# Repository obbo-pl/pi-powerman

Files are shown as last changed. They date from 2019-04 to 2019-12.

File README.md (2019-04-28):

# Pi-Powerman
  The main goal is to create a universal service operating with Raspberry Pi allowing you to control the power system. Of course, the power supply must be compatible in terms of how to communicate with the service. The current version uses I2C and two I/O ports for this purpose. The solution consists of: a service running on Raspberry and a microcontroller power supply co-operating with it. 

##### Main features:
- Easy adaptation of the power supply system,
- UPS function, automatic switching to backup power supply, battery charging and charging status monitoring,
- Automatic "shutdown" after power loss,
- Up to 8 buttons with LED (1 power button and 7 user defined),
- Ability to define extended scenarios for buttons,
- LEDs automatically indicate the state of buttons and related scenarios,
- Up to 8 connected power circuits (including 1 dedicated for Raspberry Pi),
- Cut off the power after shutting down the system,
- Monitoring of voltage, power consumption, UPS status, temperature and battery voltage,
- Export of monitored values to RRD and .txt files, .csv,
- IoT, sending messages by the MQTT protocol, 
- Communication with Raspberry via I2C and two dedicated I/O ports,
- Dedicated LED for power and Raspberry status indication.

### Requirements:
- Python 3
- Raspbian Jessie or newer

### Installation:
```
sudo apt-get update
sudo apt-get install python3-yaml python3-pip librrd-dev
sudo python3 -m pip install RPi.GPIO smbus rrdtool schedule paho-mqtt

cd /tmp
wget https://www.obbo.pl/files/articles/pi-powerman/pi-powerman.tgz
sudo mkdir /usr/local/pi-powerman
sudo tar -xf pi-powerman.tgz -C /usr/local/pi-powerman/

cd /etc/systemd/system/ 
sudo ln -s /usr/local/pi-powerman/pi-powerman.service pi-powerman.service

sudo systemctl daemon-reload
sudo systemctl enable pi-powerman.service
sudo systemctl start pi-powerman.service
```

### Hardware & Firmware.
These sections covers info on building sample hardware, including schematics, PCBs, and the corresponding firmware.

For more information: [www.obbo.pl](http://www.obbo.pl/pi-powerman)

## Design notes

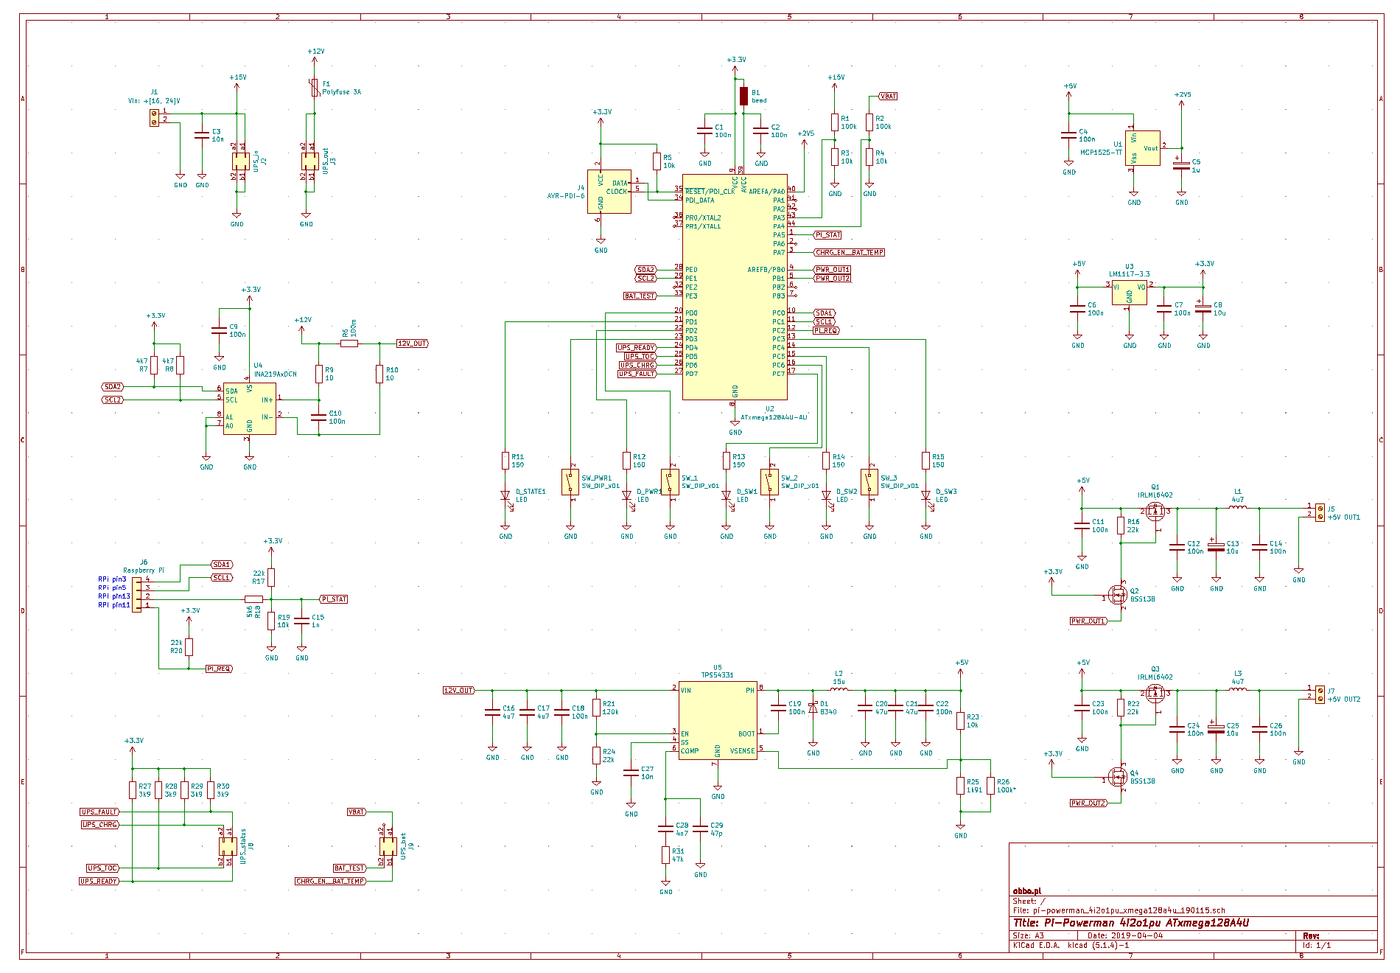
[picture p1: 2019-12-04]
hardware/pi-powerman_4i2o1pu_xmega128a4u_190115/pi-powerman_4i2o1pu_xmega128a4u_190115.png

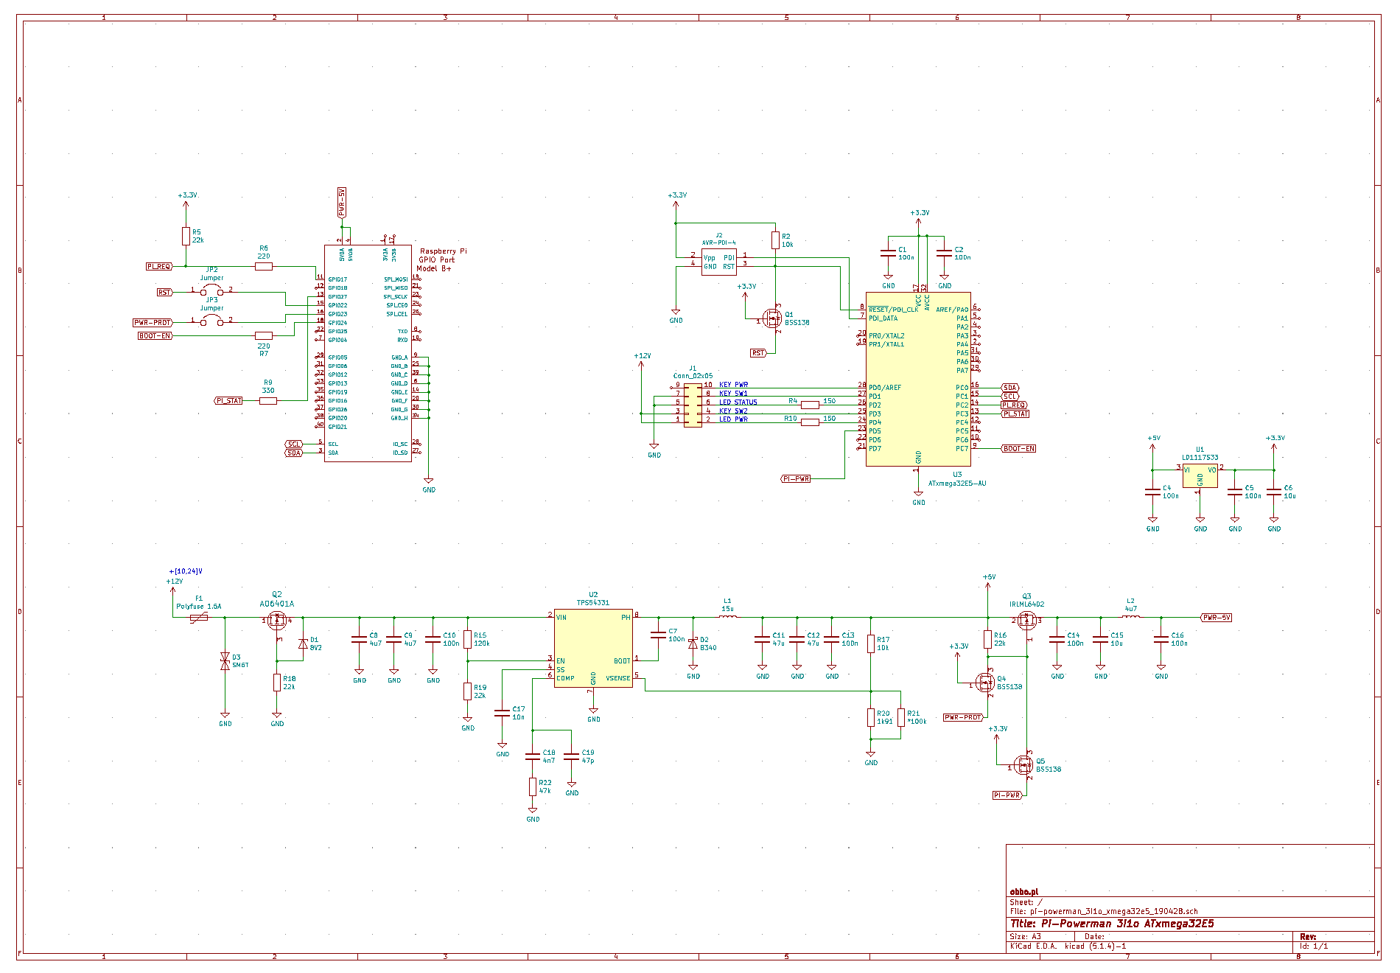
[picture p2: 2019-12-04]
hardware/pi-powerman_3i1o_xmega32e5_190428/pi-powerman_3i1o_xmega32e5_190428.png

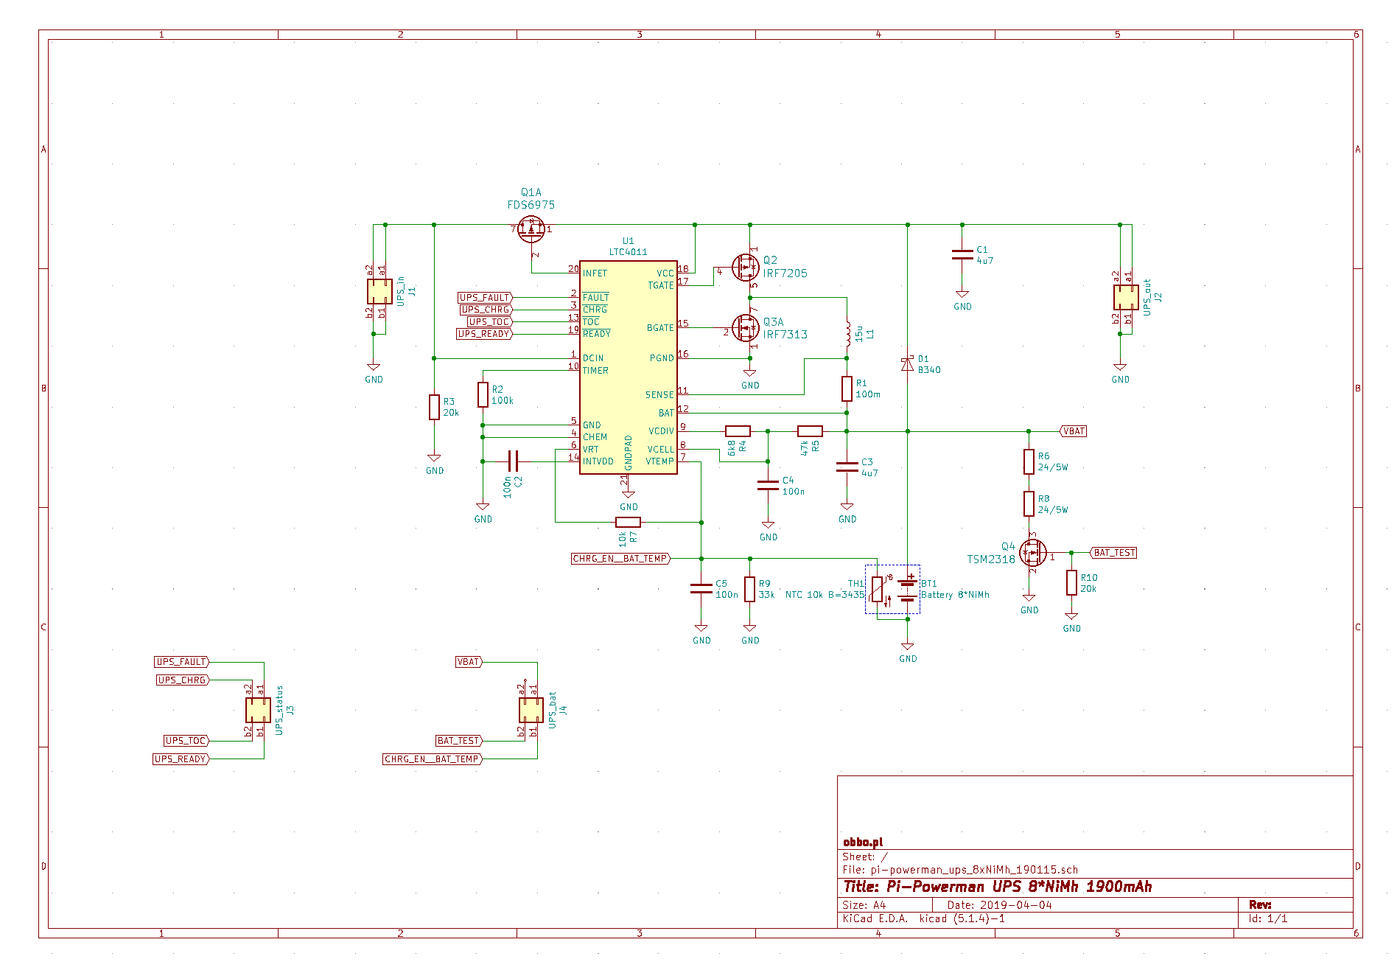
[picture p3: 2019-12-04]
hardware/pi-powerman_ups_8xNiMh_190115/pi-powerman_ups_8xNiMh_190115.png

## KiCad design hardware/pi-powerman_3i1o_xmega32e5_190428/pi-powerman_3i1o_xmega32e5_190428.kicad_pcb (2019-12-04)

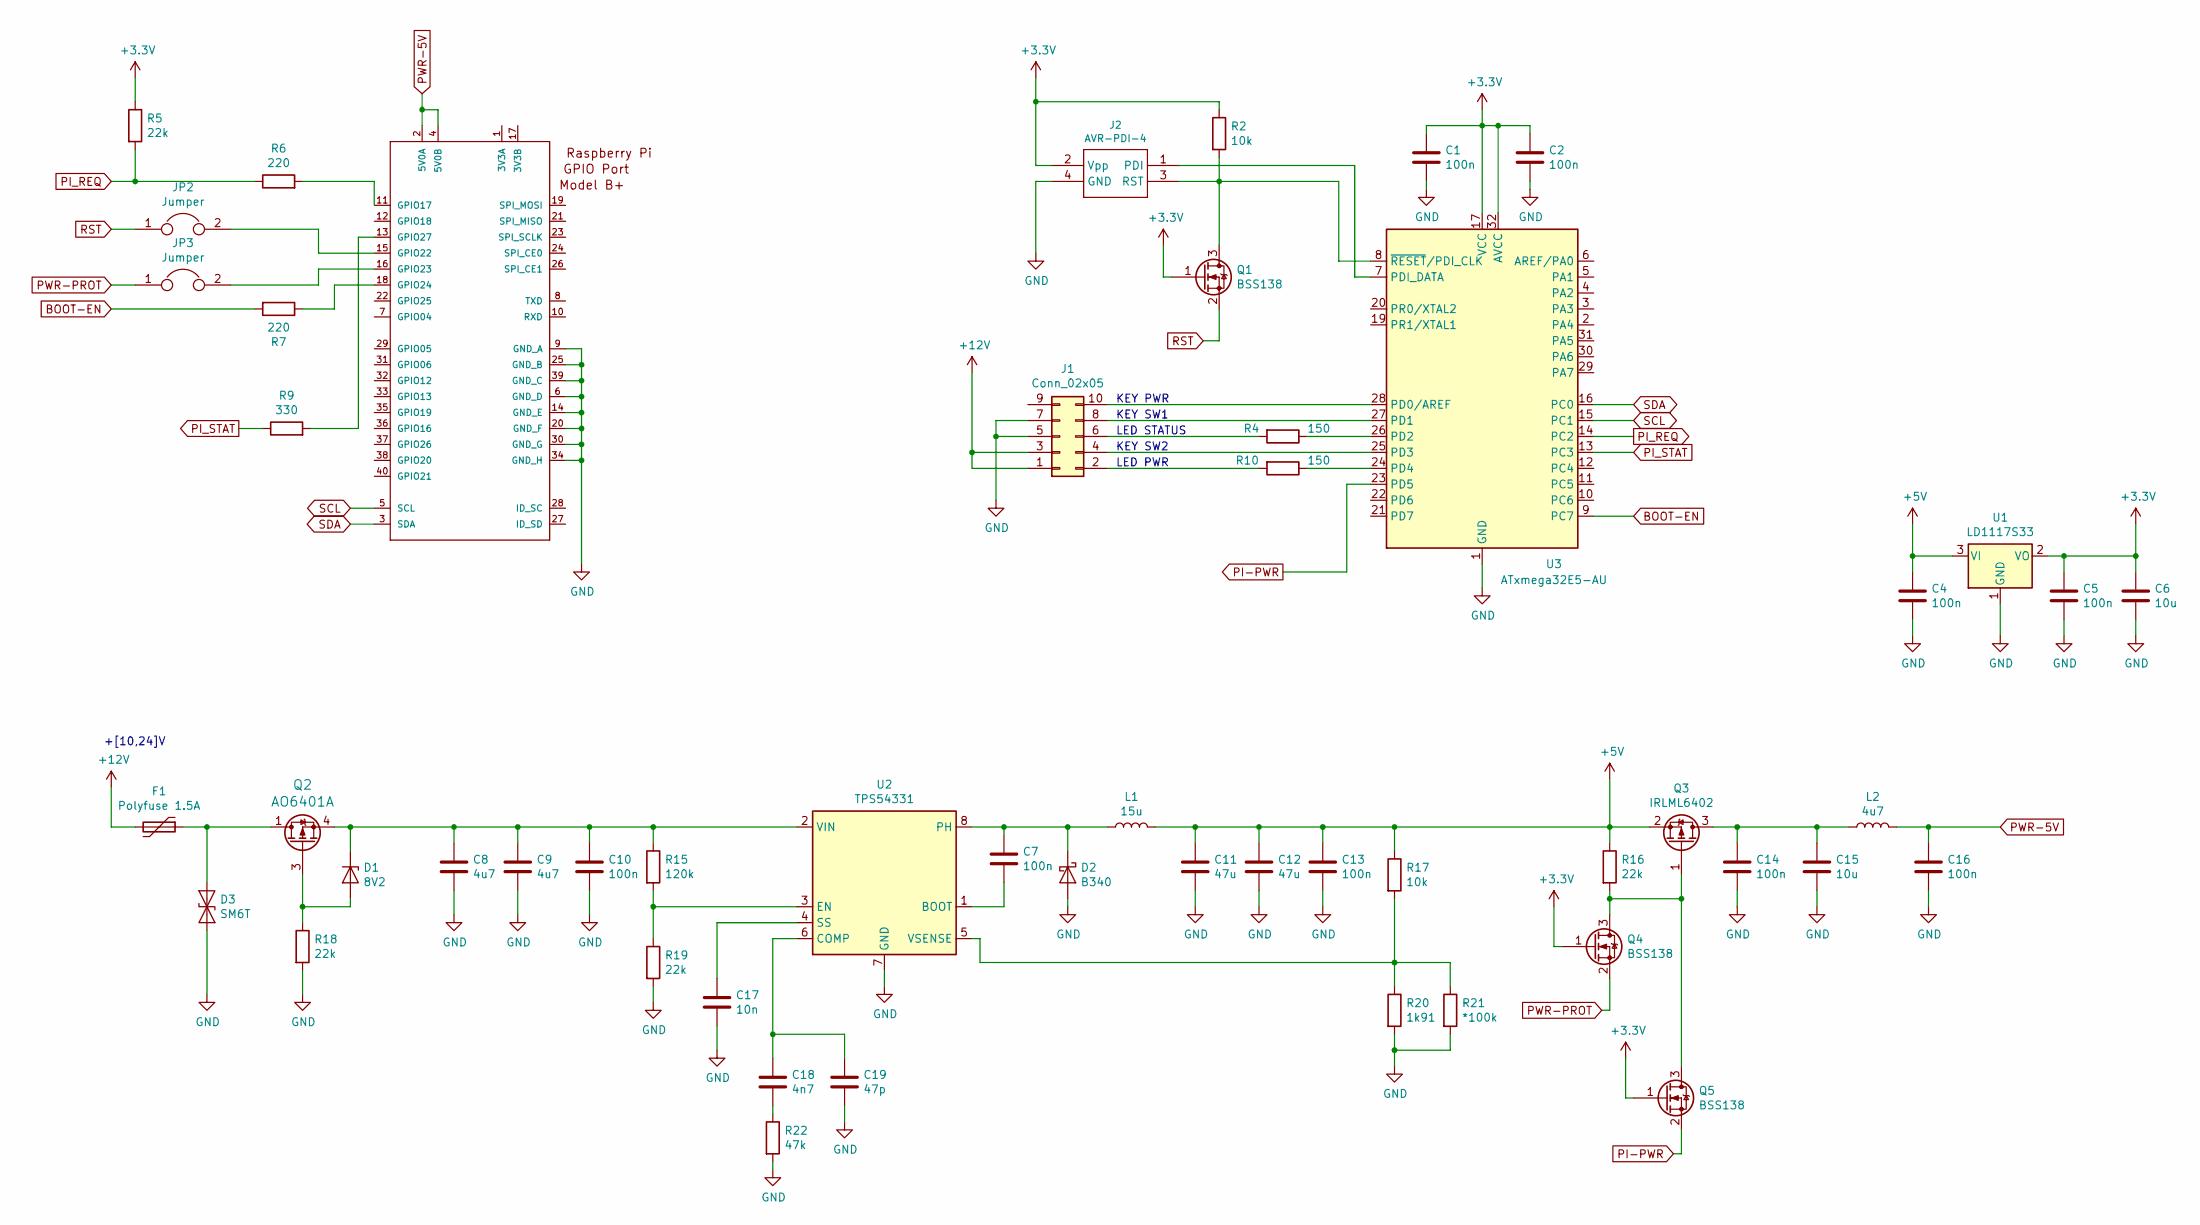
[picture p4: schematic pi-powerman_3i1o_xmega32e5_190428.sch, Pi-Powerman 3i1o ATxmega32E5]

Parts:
C1, C2, C4, C5, C10, C13, C16: 100n; C_Disc_D5.0mm_W2.5mm_P5.00mm_PAD
C6, C15: 10u; C_1206_3216Metric_Pad1.42x1.75mm_HandSolder
C7, C14: 100n; C_0805K
C8, C9: 4u7; C_1210_3225Metric_Pad1.42x2.65mm_HandSolder
C11, C12: 47u; C_1210_3225Metric_Pad1.42x2.65mm_HandSolder
C17: 10n; C_0805K
C18: 4n7; C_0805K
C19: 47p; C_0805K
CON1: RASPI_HAT_GPIO_B+-I2S; raspberrypi_RASPI_BOARD_B+HAT_SMD_V01
D1: 8V2; D_MiniMELF
D2: B340; D_SMA
D3: SM6T; D_SMB
F1: Polyfuse 1.5A; F_1812_4532Metric_Pad1.30x3.40mm_HandSolder
J1: Conn_02x05; IDC-Header_2x05_P2.54mm_SMD_Horizontal_Edge
J2: AVR-PDI-4; PinHeader_2x02_P2.54mm_Vertical_SMD
JP2, JP3: Jumper; PinHeader_1x02_P2.54mm_Horizontal_PAD
L1: 15u; L_SMD_Ferrite_X7mm_Y7mm_H4.5mm_HandSoldering
L2: 4u7; L_SMD_Ferrite_X5mm_Y5mm_H4mm_HandSoldering
Q1, Q4, Q5: BSS138; SOT-23
Q2: AO6401A; TSOP-6_1.65x3.05mm_P0.95mm
Q3: IRLML6402; SOT-23
R2, R17: 10k; R_0805K
R4, R10: 150; R_0805K
R5, R16, R18, R19: 22k; R_0805K
R6, R7: 220; R_0805K
R9: 330; R_0805K
R15: 120k; R_0805K
R20: 1k91; R_0805K
R21: *100k; R_0805K
R22: 47k; R_0805K
U1: LD1117S33; SOT-223-3_TabPin2
U2: TPS54331; SOIC-8_3.9x4.9mm_P1.27mm
U3: ATxmega32E5-AU; TQFP-32_7x7mm_P0.8mm

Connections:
+3V3: C1.1, C2.1, C5.1, C6.1, J2.2 (Vpp), Q1.1 (G), Q4.1 (G), Q5.1 (G), R2.1, R5.1, U1.2 (VO), U3.17 (VCC), U3.32 (AVCC)
+5V: C4.1, C11.1, C12.1, C13.1, L1.2, Q3.2 (S), R16.1, R17.1, U1.3 (VI)
+12V: F1.2, J1.1, J1.3
BOOT-EN: R7.2, U3.9 (PC7)
GND: C1.2, C2.2, C4.2, C5.2, C6.2, C8.2, C9.2, C10.2, C11.2, C12.2, C13.2, C14.2, C15.2, C16.2, C17.2, C19.2, CON1.6 (GND_D), CON1.9 (GND_A), CON1.14 (GND_E), CON1.20 (GND_F), CON1.25 (GND_B), CON1.30 (GND_G), CON1.34 (GND_H), CON1.39 (GND_C), D2.2 (A), D3.2 (A2), J1.5, J1.7, J2.4 (GND), R18.2, R19.2, R20.2, R21.2, R22.2, U1.1 (GND), U2.7 (GND), U3.1 (GND), U3.18 (GND)
unnamed: C7.1, D2.1 (K), L1.1, U2.8 (PH)
unnamed: C7.2, U2.1 (BOOT)
unnamed: C8.1, C9.1, C10.1, D1.1 (K), Q2.4 (S), R15.1, U2.2 (VIN)
unnamed: C14.1, C15.1, L2.1, Q3.3 (D)
unnamed: C17.1, U2.4 (SS)
unnamed: C18.1, C19.1, U2.6 (COMP)
unnamed: C18.2, R22.1
unnamed: CON1.11 (GPIO17), R6.2
unnamed: CON1.13 (GPIO27), R9.2
unnamed: CON1.15 (GPIO22), JP2.2
unnamed: CON1.16 (GPIO23), JP3.2
unnamed: CON1.18 (GPIO24), R7.1
unnamed: D1.2 (A), Q2.3 (G), R18.1
unnamed: D3.1 (A1), F1.1, Q2.1 (D), Q2.2 (D), Q2.5 (D), Q2.6 (D)
unnamed: J1.2, R10.2
unnamed: J1.4, U3.25 (PD3)
unnamed: J1.6, R4.2
unnamed: J1.8, U3.27 (PD1)
unnamed: J1.10, U3.28 (PD0/AREF)
unnamed: J2.1 (PDI), U3.7 (PDI_DATA)
unnamed: J2.3 (RST), Q1.3 (D), R2.2, U3.8 (~RESET~/PDI_CLK)
unnamed: Q3.1 (G), Q4.3 (D), Q5.3 (D), R16.2
unnamed: R4.1, U3.26 (PD2)
unnamed: R10.1, U3.24 (PD4)
unnamed: R15.2, R19.1, U2.3 (EN)
unnamed: R17.2, R20.1, R21.1, U2.5 (VSENSE)
PI-PWR: Q5.2 (S), U3.23 (PD5)
PI_REQ: R5.2, R6.1, U3.14 (PC2)
PI_STAT: R9.1, U3.13 (PC3)
PWR-5V: C16.1, CON1.2 (5V0A), CON1.4 (5V0B), L2.2
PWR-PROT: JP3.1, Q4.2 (S)
RST: JP2.1, Q1.2 (S)
SCL: CON1.5 (SCL), U3.15 (PC1)
SDA: CON1.3 (SDA), U3.16 (PC0)

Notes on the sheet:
+[10,24]V
LED STATUS
LED PWR
KEY PWR
KEY SW1
KEY SW2

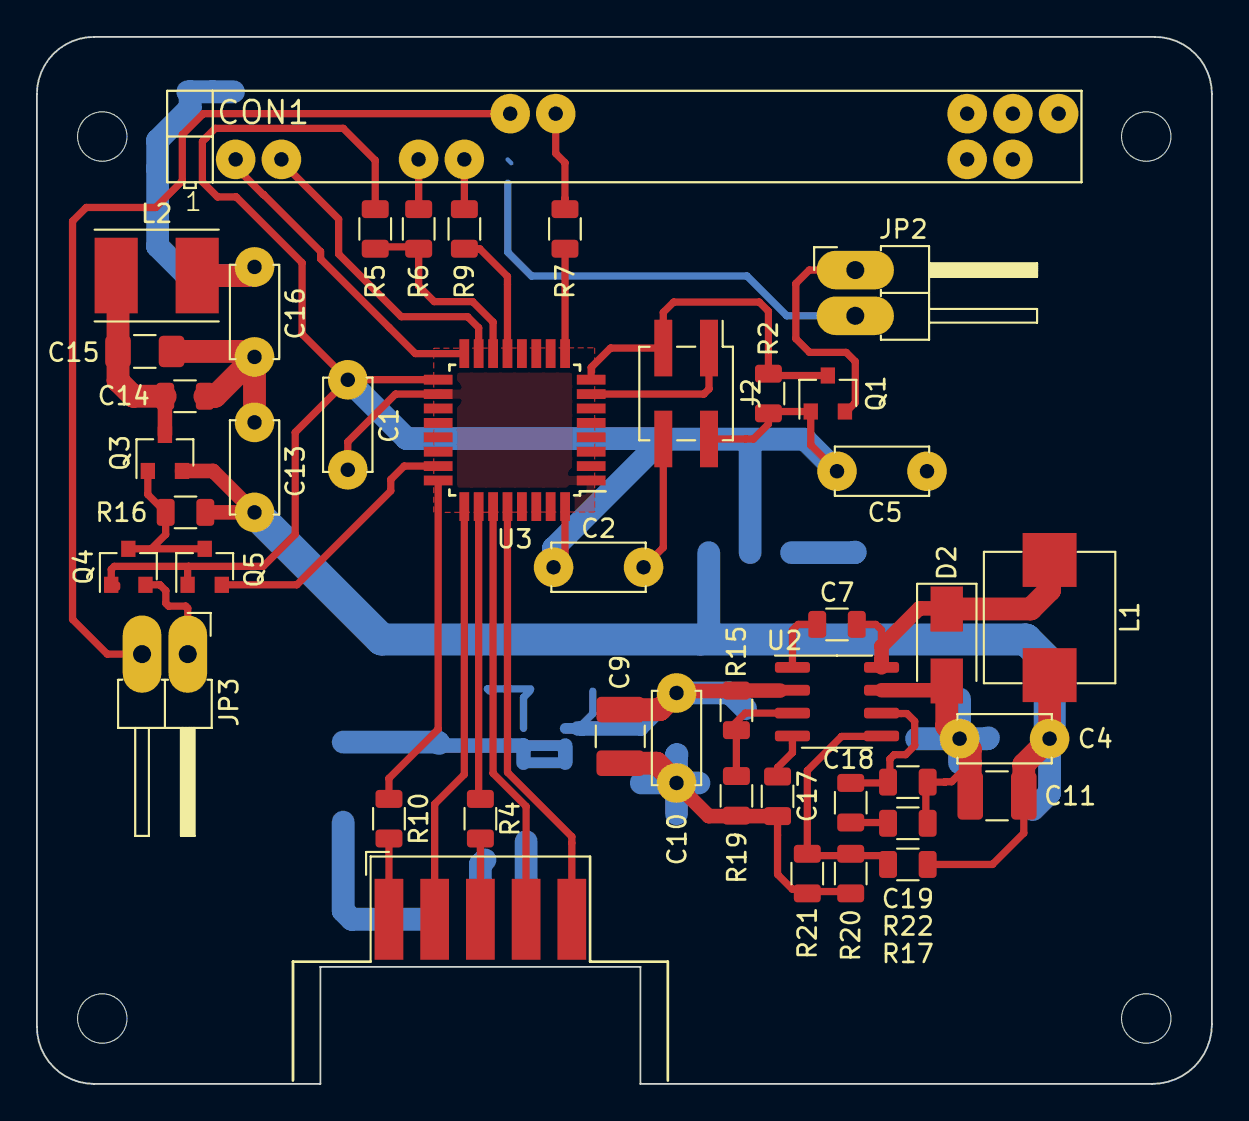
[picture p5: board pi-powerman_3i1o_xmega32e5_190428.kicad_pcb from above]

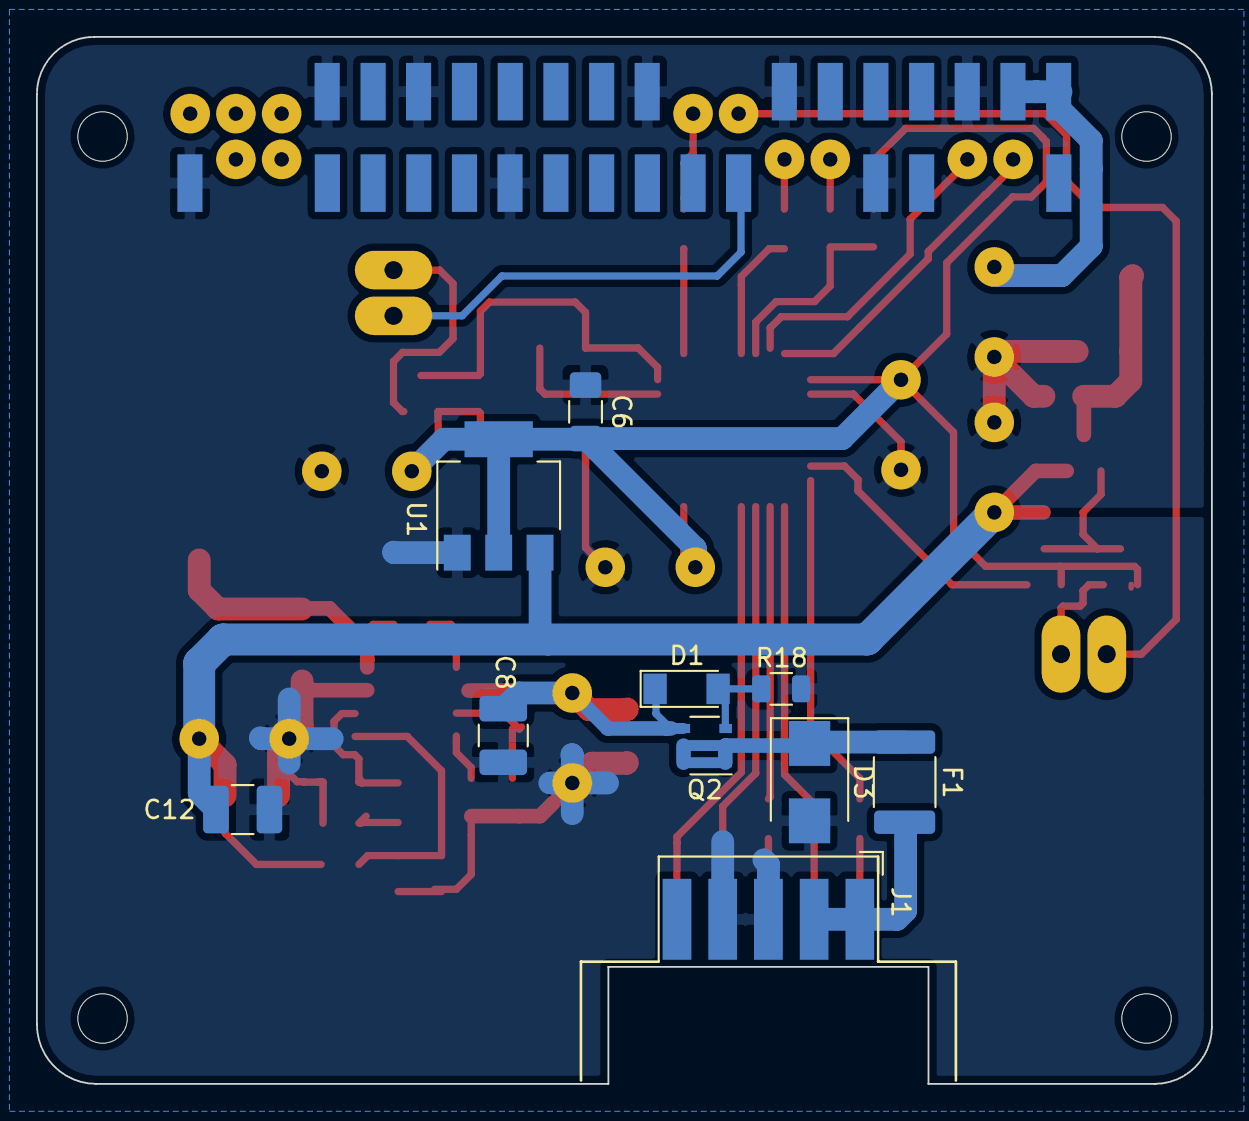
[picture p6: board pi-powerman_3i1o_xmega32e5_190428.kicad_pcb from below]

Board: 2 copper layers, 65.3 x 58.2 mm, 52 parts (10 on the bottom side), 39 nets.

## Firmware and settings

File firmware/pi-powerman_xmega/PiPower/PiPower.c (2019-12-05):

/*
 * PiPower.c
 *
 * Created: 2018-12-25 18:20:32
 * Atmel Studio 6 (Version: 6.2.1563 - Service Pack 2)
 *  Author: Krzysztof Markiewicz
 *  www.obbo.pl
 *
 * This program is distributed under the terms of the GNU General Public License
 */ 

#include "PiPower.h"
#include <avr/io.h>
#include <util/delay.h>
#include <avr/interrupt.h>
#include <avr/fuse.h>
#include <stdint.h>
#include <stdbool.h>
#include <stdio.h>
#include "pidaemon.h"
#include "macro.h"



// Hardware resources: 
// RTC  - timer Int every 50ms, control: keyboard, LED, delays
// TWIE - master, to read INA219
// TWIC - slave, to communication with Raspberry Pi
// ADC  - measure Raspberry status, voltage and temperature


FUSES = {
	.FUSEBYTE1 = 0x00,  /* Watchdog Configuration */
	.FUSEBYTE2 = 0xBD,  /* Reset Configuration */
	.FUSEBYTE4 = 0xF7,  /* Start-up Configuration */
	.FUSEBYTE5 = 0xE9,  /* EESAVE and BOD Level */
};

#define DATA_FRAME_FORMAT		0x01
#ifdef CONFIG_UPS_INSTALLED
	#define UPS_PRESENCE			0x01
#else
	#define UPS_PRESENCE			0x00
#endif
#ifdef CONFIG_KEY_PWR_port
	#define KEY_B0		1
#else
	#define KEY_B0		0
#endif
#ifdef CONFIG_KEY_SW1_port	
	#define KEY_B1		1
#else
	#define KEY_B1		0
#endif
#ifdef CONFIG_KEY_SW2_port
	#define KEY_B2		1
#else
	#define KEY_B2		0
#endif
#ifdef CONFIG_KEY_SW3_port
	#define KEY_B3		1
#else
	#define KEY_B3		0
#endif
#ifdef CONFIG_KEY_SW4_port
	#define KEY_B4		1
#else
	#define KEY_B4		0
#endif
#ifdef CONFIG_KEY_SW5_port
	#define KEY_B5		1
#else
	#define KEY_B5		0
#endif
#ifdef CONFIG_KEY_SW6_port
	#define KEY_B6		1
#else
	#define KEY_B6		0
#endif
#ifdef CONFIG_KEY_SW7_port
	#define KEY_B7		1
#else
	#define KEY_B7		0
#endif
#define BUTTON_PRESENCE		gluebyte(KEY_B7, KEY_B6, KEY_B5, KEY_B4, KEY_B3, KEY_B2, KEY_B1, KEY_B0)
#ifdef CONFIG_LED_PWR_port
	#define LED_B0		1
#else
	#define LED_B0		0
#endif
#ifdef CONFIG_LED_SW1_port
	#define LED_B1		1
#else
	#define LED_B1		0
#endif
#ifdef CONFIG_LED_SW2_port
	#define LED_B2		1
#else
	#define LED_B2		0
#endif
#ifdef CONFIG_LED_SW3_port
	#define LED_B3		1
#else
	#define LED_B3		0
#endif
#ifdef CONFIG_LED_SW4_port
	#define LED_B4		1
#else
	#define LED_B4		0
#endif
#ifdef CONFIG_LED_SW5_port
	#define LED_B5		1
#else
	#define LED_B5		0
#endif
#ifdef CONFIG_LED_SW6_port
	#define LED_B6		1
#else
	#define LED_B6		0
#endif
#ifdef CONFIG_LED_SW7_port
	#define LED_B7		1
#else
	#define LED_B7		0
#endif
#define LED_PRESENCE		gluebyte(LED_B7, LED_B6, LED_B5, LED_B4, LED_B3, LED_B2, LED_B1, LED_B0)
#ifdef CONFIG_POWEROUT_Pi_port
	#define OUT_B0		1
#else
	#define OUT_B0		0
#endif
#ifdef CONFIG_POWEROUT_1_port
	#define OUT_B1		1
#else
	#define OUT_B1		0
#endif
#ifdef CONFIG_POWEROUT_2_port
	#define OUT_B2		1
#else
	#define OUT_B2		0
#endif
#ifdef CONFIG_POWEROUT_3_port
	#define OUT_B3		1
#else
	#define OUT_B3		0
#endif
#ifdef CONFIG_POWEROUT_4_port
	#define OUT_B4		1
#else
	#define OUT_B4		0
#endif
#ifdef CONFIG_POWEROUT_5_port
	#define OUT_B5		1
#else
	#define OUT_B5		0
#endif
#ifdef CONFIG_POWEROUT_6_port
	#define OUT_B6		1
#else
	#define OUT_B6		0
#endif
#ifdef CONFIG_POWEROUT_7_port
	#define OUT_B7		1
#else
	#define OUT_B7		0
#endif
#define OUTPUT_PRESENCE		gluebyte(OUT_B7, OUT_B6, OUT_B5, OUT_B4, OUT_B3, OUT_B2, OUT_B1, OUT_B0)
#ifdef CONFIG_LED_STATUS_port
	#define LED_STATUS_PRESENCE		0x01
#else 
	#define LED_STATUS_PRESENCE		0x00
#endif
#ifdef CONFIG_ADC_MEASUREMENT_INSTALLED
	#define ADC_MEASURE_PRESENCE	0x07
#else
	#define ADC_MEASURE_PRESENCE	0x00
#endif
#ifdef CONFIG_I2C_MEASUREMENT_INSTALLED
	#define I2C_1MEASURE_PRESENCE	0x01
	#define I2C_2MEASURE_PRESENCE	0x01
	#define I2C_3MEASURE_PRESENCE	0x01
#else
	#define I2C_1MEASURE_PRESENCE	0x00
	#define I2C_2MEASURE_PRESENCE	0x00
	#define I2C_3MEASURE_PRESENCE	0x00
#endif
#define VERSION_MAJOR			"0"
#define VERISON_MINOR			"8"
const char DEVICE_INFO_0[OUTPUT_BUFFER_SIZE]	PROGMEM = {DATA_FRAME_FORMAT, UPS_PRESENCE, BUTTON_PRESENCE, LED_PRESENCE,
														OUTPUT_PRESENCE, LED_STATUS_PRESENCE, ADC_MEASURE_PRESENCE, I2C_1MEASURE_PRESENCE,
														I2C_2MEASURE_PRESENCE, I2C_3MEASURE_PRESENCE};
const char DEVICE_INFO_1[OUTPUT_BUFFER_SIZE]	PROGMEM = "HW: Pi-Powerman." VERSION_MAJOR "." VERISON_MINOR " "; 
const char DEVICE_INFO_2[OUTPUT_BUFFER_SIZE]	PROGMEM = "(Build: " __DATE__ " " __TIME__ ")";
#ifdef CONFIG_UPS_INSTALLED
	const char DEVICE_INFO_3[OUTPUT_BUFFER_SIZE]	PROGMEM = "UPS: " CONFIG_UPS_TYPE;
#else
	const char DEVICE_INFO_3[OUTPUT_BUFFER_SIZE]	PROGMEM = "no UPS";
#endif

OB_LED_t led_pwr;
OB_LED_t led_status;
OB_LED_t led_sw1;
OB_LED_t led_sw2;
OB_LED_t led_sw3;
OB_LED_t led_sw4;
OB_LED_t led_sw5;
OB_LED_t led_sw6;
OB_LED_t led_sw7;
OB_LED_t *led_sw_all[LED_MAX_COUNT];

OB_KEY_t key_pwr;
OB_KEY_t key_sw1;
OB_KEY_t key_sw2;
OB_KEY_t key_sw3;
OB_KEY_t key_sw4;
OB_KEY_t key_sw5;
OB_KEY_t key_sw6;
OB_KEY_t key_sw7;
OB_KEY_t *key_sw_all[KEY_MAX_COUNT];

OB_POWEROUT_t powerout_outpi;
OB_POWEROUT_t powerout_out1;
OB_POWEROUT_t powerout_out2;
OB_POWEROUT_t powerout_out3;
OB_POWEROUT_t powerout_out4;
OB_POWEROUT_t powerout_out5;
OB_POWEROUT_t powerout_out6;
OB_POWEROUT_t powerout_out7;
OB_POWEROUT_t *powerout_out_all[POWEROUT_MAX_COUNT];

// Default setup values
uint16_t EEMEM adc_vin_cal = 10403;
uint16_t EEMEM adc_vbat_cal = 9945;
uint8_t EEMEM main_on_boot_output = (1 << POWEROUT_OUTPUT_3);
uint16_t EEMEM main_on_boot_delay_s = 3;
uint16_t EEMEM main_on_down_delay_s = 5;
uint8_t EEMEM main_on_pioff_output = (1 << POWEROUT_OUTPUT_3);
uint16_t EEMEM main_on_pioff_delay_s = 3;
uint16_t EEMEM main_daemon_timeout_s = 150;
uint8_t EEMEM main_error_recoverable = ((1 << MAIN_ERROR_TIMEOUT_DAEMON) | (1 << MAIN_ERROR_DAEMON));
uint8_t EEMEM ups_behavior = UPS_SHUT_DELAYED;
uint16_t EEMEM ups_delay_s = 180;
uint16_t EEMEM ups_cut_level_mv = 8000;
uint16_t EEMEM ups_min_charge_time_s = 30;
uint16_t EEMEM battery_overheat_01k = 33500;
uint16_t EEMEM main_power_loss_mv = 7000;
uint16_t EEMEM dummy = 0x1111;

COUNTER_t timer_rtc_ms;
COUNTER_t delay_on_boot_s;
COUNTER_t delay_on_down_s;
COUNTER_t delay_on_pioff_s;
COUNTER_t daemon_timeout_s;
COUNTER_t after_power_loss_s;
COUNTER_t adc_conversion_timeout_ms;
COUNTER_t adc_maesurement_ready;

LPFu16_t lpf_voltage_in;
LPFu16_t lpf_voltage_battery;
LPFu16_t lpf_temperature;

// Prototypes of functions 
void main_MapStatusToBuffer();
void main_MapSetupToBuffer();
void main_ReadSetup(void);
void twi_SlaveProcessData(void);
void main_ADCInitConversion(uint8_t mux);
void main_ClearButtonState();
void main_NewButtonState(uint8_t button, uint8_t state);
void main_LedInit(void);
void main_LedPwrOn(void);
void main_LedPwrOff(void);
void main_LedStatusOn(void);
void main_LedStatusOff(void);
void main_LedSw1On(void);
void main_LedSw1Off(void);
void main_LedSw2On(void);
void main_LedSw2Off(void);
void main_LedSw3On(void);
void main_LedSw3Off(void);
void main_LedSw4On(void);
void main_LedSw4Off(void);
void main_LedSw5On(void);
void main_LedSw5Off(void);
void main_LedSw6On(void);
void main_LedSw6Off(void);
void main_LedSw7On(void);
void main_LedSw7Off(void);
void main_KeyboardInit(void);
uint8_t main_ReadKeyPwr(void);
uint8_t main_ReadKeySw1(void);
uint8_t main_ReadKeySw2(void);
uint8_t main_ReadKeySw3(void);
uint8_t main_ReadKeySw4(void);
uint8_t main_ReadKeySw5(void);
uint8_t main_ReadKeySw6(void);
uint8_t main_ReadKeySw7(void);
void main_PoweroutInit(void);
void main_SetPoweroutOutPi(uint8_t state);
uint8_t main_ReadPoweroutOutPi(void);
void main_SetPoweroutOut1(uint8_t state);
uint8_t main_ReadPoweroutOut1(void);
void main_SetPoweroutOut2(uint8_t state);
uint8_t main_ReadPoweroutOut2(void);
void main_SetPoweroutOut3(uint8_t state);
uint8_t main_ReadPoweroutOut3(void);
void main_SetPoweroutOut4(uint8_t state);
uint8_t main_ReadPoweroutOut4(void);
void main_SetPoweroutOut5(uint8_t state);
uint8_t main_ReadPoweroutOut5(void);
void main_SetPoweroutOut6(uint8_t state);
uint8_t main_ReadPoweroutOut6(void);
void main_SetPoweroutOut7(uint8_t state);
uint8_t main_ReadPoweroutOut7(void);
uint8_t main_CheckOutput(OB_POWEROUT_t **all);
void main_RC32MClockInit(uint8_t timeoutms);
void main_RTCInit();
void main_ClearButtonRequest();
void main_CopyToTWIBuffer(uint8_t *source, register8_t *dest);
void main_CopyFromTWIBuffer(register8_t *source, uint8_t *dest);
void main_CopyCharToTWIBuffer(const char *source, register8_t *dest);
void main_SaveSetup(void);
void main_SendSetup(register8_t *dest);
void main_PowerReduction(void);
void main_MapButtonsState(void);
void CCPWrite( volatile uint8_t *address, uint8_t value );


int main(void)
{
	main_MapStatusToBuffer();
	main_MapSetupToBuffer();
	// Initialize system clock
	main_RC32MClockInit(MAIN_TIMEOUT_MAINCLOCK_MS);
	main_RTCInit();
	// Read setup from EEMEM
	main_ReadSetup();
	// Initialize power output
	main_PoweroutInit();
	// Initialize keyboard
	main_KeyboardInit();
	// Initialize LED's
	main_LedInit();
	// Initialize wired to RasPi (INT_request, RasPi_state) 
	pidaemon_Init();
#ifdef CONFIG_ADC_MEASUREMENT_INSTALLED	
	// Initialize ADC
	adc_Setup();
#endif
	// Initialize TWI slave
	TWI_SlaveInitializeDriver(&twiSlave, &TWIC, twi_SlaveProcessData);
	TWI_SlaveInitializeModule(&twiSlave, TWI_SLAVE_ADDRESS, TWI_SLAVE_INTLVL_HI_gc);
#ifdef CONFIG_I2C_MEASUREMENT_INSTALLED
	// Initialize TWI master
	TWI_MasterInit(&twiMaster, &TWIE, TWI_MASTER_INTLVL_MED_gc, TWI_BAUDSETTING);
#endif
#ifdef CONFIG_UPS_INSTALLED
	// Initialize UPS
	ups_Init(&ups);
#endif
    // Power reduction
	main_PowerReduction();
	// Initialize IRQ
    PMIC.CTRL = PMIC_HILVLEN_bm | PMIC_MEDLVLEN_bm | PMIC_LOLVLEN_bm;
    sei();
	_delay_ms(10);
#ifdef CONFIG_I2C_MEASUREMENT_INSTALLED
    // Initialize INA219
	bool result = ina219_Init(&ina219, &twiMaster, 0x40);
	_delay_ms(10);
	result &= ina219_SetCalibration_12bit(&ina219, INA219_CONFIG_BVOLTAGERANGE_32V, INA219_CONFIG_GAIN_8_320MV, 0.1, 0.1);
	if (!result) setbit(*(pipo_status.errors), MAIN_ERROR_INA219);
#endif
	// Set button state to all off
	main_ClearButtonState();
#ifdef CONFIG_ADC_MEASUREMENT_INSTALLED
	// Start ADC conversion
	main_ADCInitConversion(adc_CurrentInput());
#endif
	// Initialize delays and LowPass filters
	counter_Init(&timer_rtc_ms, MAIN_TIMER_RTC_TO_1S);
	counter_Init(&daemon_timeout_s, *(pipo_setup.daemon_timeout_s));
	counter_Pause(&daemon_timeout_s);
#ifdef CONFIG_UPS_INSTALLED
	counter_Init(&after_power_loss_s, *(pipo_setup.ups_shut_delay_s));
	counter_Pause(&after_power_loss_s);
#endif
	counter_Init(&adc_conversion_timeout_ms, MAIN_TIMER_ADCCONVERSION_MS);
	counter_Pause(&adc_conversion_timeout_ms);
	counter_Init(&adc_maesurement_ready, ADC_SKIP_FIRST_MEASURE);
	uint8_t last_error = 0;
	lpfilter_Set(&lpf_voltage_in, 10);
	lpfilter_Set(&lpf_voltage_battery, 8);
	lpfilter_Set(&lpf_temperature, 8);
	uint8_t request;
#ifdef CONFIG_I2C_MEASUREMENT_INSTALLED
	uint8_t ina219_request = 0;
#endif
	// start the main loop, the loop should take less then 50ms (MAIN_TIMER_KEBOARD_MS)
    while(1)
    {	
		// Scan the keyboard
		if(testbit(main_request, MAIN_REQUEST_SCAN_KEYBOARD)) {
			clrbit(main_request, MAIN_REQUEST_SCAN_KEYBOARD);
			for (int i = KEYBOARD_KEY_PWR; i < KEY_MAX_COUNT; i++) {
				key_UpdateKeyStatus(key_sw_all[i]);
			}
		}
		// On key press action
		// Power Button, switch to On
		if (testbit(key_CheckKey(&key_pwr), KEYBOARD_KeyStatusPressed)) {
			if (pipo_status.buttons->state[KEYBOARD_KEY_PWR] == BUTTON_STATE_OFF) {
				led_SetLed(&led_pwr, true, true);
				for (int i = POWEROUT_OUTPUT_1; i < POWEROUT_MAX_COUNT; i++) {
					if (testbit(*(pipo_setup.on_boot_output), i)) powerout_SetOn(powerout_out_all[i]);					
				}
				counter_Init(&delay_on_boot_s, *(pipo_setup.on_boot_delay_s));
				main_NewButtonState(KEYBOARD_KEY_PWR, BUTTON_STATE_TURN_ON_01);
				key_ClearKey(&key_pwr);
			}
		}
		if (pipo_status.buttons->state[KEYBOARD_KEY_PWR] == BUTTON_STATE_TURN_ON_01) {
			if (counter_Check(&delay_on_boot_s)) {
				main_ClearButtonRequest();
				powerout_SetOn(&powerout_outpi);
				main_NewButtonState(KEYBOARD_KEY_PWR, BUTTON_STATE_TURN_ON_02);
			}
		}
		if (pipo_status.buttons->state[KEYBOARD_KEY_PWR] == BUTTON_STATE_TURN_ON_02) {
			if (*pipo_status.daemon == PIDAEMON_STATE_HIGH) {
				led_SetLed(&led_pwr, true, false);
				main_NewButtonState(KEYBOARD_KEY_PWR, BUTTON_STATE_ON);
				counter_Reset(&daemon_timeout_s);
				for (int i = KEYBOARD_KEY_PWR; i < KEY_MAX_COUNT; i++) {
					if (key_sw_all[i]->presence) key_ClearKey(key_sw_all[i]);
				}				
			}
		}
		// Power Button, switch to Off
		request = button_request[KEYBOARD_KEY_PWR];
		if (testbit(key_CheckKey(&key_pwr), KEYBOARD_KeyStatusPressed) || (request == BUTTON_STATE_PRESS) || (request == BUTTON_STATE_OFF)) {
			if (pipo_status.buttons->state[KEYBOARD_KEY_PWR] == BUTTON_STATE_ON) {
				led_SetLed(&led_pwr, true, true);
				counter_Pause(&daemon_timeout_s);
				main_NewButtonState(KEYBOARD_KEY_PWR, BUTTON_STATE_TURN_OFF_01);
				// On BUTTON_STATE_TURN_OFF_01 RasPi should initiate shutdown procedure
				key_ClearKey(&key_pwr);
				button_request[KEYBOARD_KEY_PWR] = BUTTON_STATE_IDLE;
			}
		}
		if (pipo_status.buttons->state[KEYBOARD_KEY_PWR] == BUTTON_STATE_TURN_OFF_01) {
			if (*pipo_status.daemon != PIDAEMON_STATE_HIGH) {
				counter_Init(&delay_on_down_s, *(pipo_setup.on_down_delay_s));
				main_NewButtonState(KEYBOARD_KEY_PWR, BUTTON_STATE_TURN_OFF_02);
			}
			counter_Pause(&daemon_timeout_s);
		}
		if (pipo_status.buttons->state[KEYBOARD_KEY_PWR] == BUTTON_STATE_TURN_OFF_02) {
			if (counter_Check(&delay_on_down_s)) {
				for (int i = POWEROUT_OUTPUT_Pi; i < POWEROUT_MAX_COUNT; i++) {
					if (!(testbit(*(pipo_setup.on_pioff_output), i))) powerout_SetOff(powerout_out_all[i]);
				}
				counter_Init(&delay_on_pioff_s, *(pipo_setup.on_pioff_delay_s));
				main_NewButtonState(KEYBOARD_KEY_PWR, BUTTON_STATE_TURN_OFF_03);
			}
		}	
		if (pipo_status.buttons->state[KEYBOARD_KEY_PWR] == BUTTON_STATE_TURN_OFF_03) {
			if (counter_Check(&delay_on_pioff_s)) {
				for (int i = POWEROUT_OUTPUT_Pi; i < POWEROUT_MAX_COUNT; i++) {
					if (testbit(*(pipo_setup.on_pioff_output), i)) powerout_SetOff(powerout_out_all[i]);
				}
				main_NewButtonState(KEYBOARD_KEY_PWR, BUTTON_STATE_OFF);
				for (int i = 0; i < LED_MAX_COUNT; i++) {
					led_SetLed(led_sw_all[i], false, false);
				}
				main_ClearButtonState();
				main_ClearButtonRequest();
			}
		}
		if (pipo_status.buttons->state[KEYBOARD_KEY_PWR] == BUTTON_STATE_ON) {
			// Scan buttons
			for (int i = KEYBOARD_KEY_SW1; i < KEY_MAX_COUNT; i++) {
				if (key_sw_all[i]->presence) {
					request = button_request[i];
					if (testbit(key_CheckKey(key_sw_all[i]), KEYBOARD_KeyStatusPressed) || (request == BUTTON_STATE_PRESS) || (request == BUTTON_STATE_ON)) {
						if (pipo_status.buttons->state[i] == BUTTON_STATE_OFF) {
							if (led_sw_all[i]->presence) led_SetLed(led_sw_all[i], true, true);
							main_NewButtonState(i, BUTTON_STATE_TURN_ON_01);
							key_ClearKey(key_sw_all[i]);
							button_request[i] = BUTTON_STATE_IDLE;
						}
					}
					if (testbit(key_CheckKey(key_sw_all[i]), KEYBOARD_KeyStatusPressed) || (request == BUTTON_STATE_PRESS) || (request == BUTTON_STATE_OFF)) {
						if (pipo_status.buttons->state[i] == BUTTON_STATE_ON) {
							if (led_sw_all[i]->presence) led_SetLed(led_sw_all[i], true, true);
							main_NewButtonState(i, BUTTON_STATE_TURN_OFF_01);
							key_ClearKey(key_sw_all[i]);
							button_request[i] = BUTTON_STATE_IDLE;
						}
					}
				} else {
					button_request[i] = BUTTON_STATE_IDLE;
				}
			}
		}
		// Set LEDs
		for (int i = KEYBOARD_KEY_SW1; i < KEY_MAX_COUNT; i++) {
			if (led_sw_all[i]->presence) {
				if (pipo_status.buttons->state[i] == BUTTON_STATE_DISABLE) led_SetLed(led_sw_all[i], false, false);
				if (pipo_status.buttons->state[i] == BUTTON_STATE_OFF) led_SetLed(led_sw_all[i], false, false);
				if (pipo_status.buttons->state[i] == BUTTON_STATE_ON) led_SetLed(led_sw_all[i], true, false);
			}
		}
		// Update LED
		if(testbit(main_request, MAIN_REQUEST_UPDATE_LED)) {
			clrbit(main_request, MAIN_REQUEST_UPDATE_LED);
#ifdef CONFIG_LED_STATUS_port
			led_UpdateStatus(&led_status);
#endif
			for (int i = 0; i < LED_MAX_COUNT; i++) {
				led_UpdateStatus(led_sw_all[i]);
			}
		}
#ifdef CONFIG_ADC_MEASUREMENT_INSTALLED
		// Set MUX and start ADC conversion
		if (testbit(main_request, MAIN_REQUEST_ADC_READY)) {
			uint16_t v = adc_ReadInput();
	#ifdef CONFIG_UPS_INSTALLED
			float volt;
	#endif
			switch(adc_CurrentInput()) {
				case CONFIG_ADC_MUX_PiState:
	#ifndef	CONFIG_PIDAEMON_LOGIC_LEVEL_CHECK
					*(pipo_status.daemon) = pidaemon_CheckDaemonState(v);
	#endif
					counter_Update(&adc_maesurement_ready, 1);
					break;
				case CONFIG_ADC_MUX_V_In:
				    *(pipo_status.adc_V_In) = (uint16_t)((*(pipo_setup.calibration_vin) / 10000.0) * lpfilter_Filter(&lpf_voltage_in, v) * 2500 / 4096);
					break;
	#ifdef CONFIG_UPS_INSTALLED
				case CONFIG_ADC_MUX_V_Bat:
					*(pipo_status.adc_V_Bat) = (uint16_t)((*(pipo_setup.calibration_vbat) / 10000.0) * lpfilter_Filter(&lpf_voltage_battery, v) * 2500 / 4096);
					break;
				case CONFIG_ADC_MUX_BAT_Temp:
					volt = lpfilter_Filter(&lpf_temperature, v) * 2.5 / 4096;
					*(pipo_status.adc_BAT_Temp) = ups_NTCTermistorToKelvin(volt);
					// incorrect temperature readings can cause an overheating alarm
					// when the charging is disabled, the temperature measurement is not available
					if (ups.charge_disabled) {
						counter_Reset(&adc_maesurement_ready);
						*(pipo_status.adc_BAT_Temp) = 0;
					}
					break;
	#endif
			}
			main_ADCInitConversion(adc_NextInput());
		}
#endif
#ifdef	CONFIG_PIDAEMON_LOGIC_LEVEL_CHECK
		*(pipo_status.daemon) = pidaemon_CheckDaemonState((CONFIG_PIDAEMON_STATE_PORT.IN >> CONFIG_PIDAEMON_STATE_PIN) & 0x01);
#endif
		// Power supply outputs, check the change request
		if (output_request[0]) {
			for (int i = 0; i < POWEROUT_MAX_COUNT; i++) {
				// skip Raspberry Pi supply output
				if (i == POWEROUT_OUTPUT_Pi) continue;
				if (testbit(output_request[0], i)) {
					if (powerout_out_all[i]->presence) {
						if (testbit(output_request[1], i)) {
							powerout_SetOn(powerout_out_all[i]);
						} else {
							powerout_SetOff(powerout_out_all[i]);
						}
					}
					clrbit(output_request[0], i);
				}
			}
		}		
		// Power supply outputs, check the current state
		*pipo_status.output = main_CheckOutput(powerout_out_all);			
#ifdef CONFIG_UPS_INSTALLED 
		// Check UPS state
		*pipo_status.ups = ups_CheckStatus(&ups);
#endif
#ifdef CONFIG_I2C_MEASUREMENT_INSTALLED
		// Read INA219, one request per loop
		switch(ina219_request) {
			uint16_t ina219_result;
			
			result = true;
			case INA219_REQUEST_VOLTAGE:
				result = ina219_GetRawBusVoltage(&ina219, &ina219_result);
				if (result && ina219.ready) pipo_status.ina219->voltage = ina219_result;
				break;
			case INA219_REQUEST_CURRENT:
				result = ina219_GetRawCurrent(&ina219, (int16_t *)(&ina219_result));
				if (result && ina219.ready) pipo_status.ina219->current = ina219_result;
				break;
		}
		if (!result) setbit(*(pipo_status.errors), MAIN_ERROR_INA219);
		ina219_request++;
		if (ina219_request > INA219_REQUEST_COUNT) ina219_request = 0; 
#endif
#ifdef CONFIG_UPS_INSTALLED
		// Action on the main power loss
		// adc_V_In LSB = 0.01V, adc_V_Bat LSB = 0.01V
		if (counter_Check(&adc_maesurement_ready)) {
			uint16_t cut_level = trunc(*(pipo_setup.ups_cut_level_mv) / 10);
			if (*pipo_status.adc_V_In < *(pipo_setup.power_loss_level_mv)) {
				if (after_power_loss_s.pause) counter_Reset(&after_power_loss_s);
				if ((*(pipo_setup.ups_behavior) == UPS_SHUT_IMMEDIATELY) || ((*(pipo_setup.ups_behavior) == UPS_SHUT_DELAYED) && 
												   (counter_Check(&after_power_loss_s))) || (*pipo_status.adc_V_Bat < cut_level)) {
					button_request[KEYBOARD_KEY_PWR] = BUTTON_STATE_OFF;
					ups_OnBattery(&ups, true);
				}
			} else {
				if (!(after_power_loss_s.pause)) {
					counter_Reset(&after_power_loss_s);
					counter_Pause(&after_power_loss_s);
				}
				ups_OnBattery(&ups, false);
			}
		}
#endif
#ifdef CONFIG_UPS_INSTALLED
		// Check battery overheat, temperature LSB = 0.01K
		if (counter_Check(&adc_maesurement_ready)) {
			if (*pipo_status.adc_BAT_Temp > *(pipo_setup.battery_overheat)) {
				setbit(*(pipo_status.errors), MAIN_ERROR_BATTERY_OVERHEAT);
				button_request[KEYBOARD_KEY_PWR] = BUTTON_STATE_OFF;
			} else {
				if (testbit(*(pipo_setup.error_recoverable), MAIN_ERROR_BATTERY_OVERHEAT)) clrbit(*(pipo_status.errors), MAIN_ERROR_BATTERY_OVERHEAT); 
			}
		}
#endif
		// Check for errors
		if  (counter_Check(&daemon_timeout_s)) {
			setbit(*(pipo_status.errors), MAIN_ERROR_TIMEOUT_DAEMON);
		} else {
			if (testbit(*(pipo_setup.error_recoverable), MAIN_ERROR_TIMEOUT_DAEMON)) clrbit(*(pipo_status.errors), MAIN_ERROR_TIMEOUT_DAEMON);
		}
		if (*(pipo_status.errors) != last_error) {
			pidaemon_SetRequest();
			last_error = *(pipo_status.errors);
			if (last_error) {
				led_SetLed(&led_status, true, true);
			} else {
				led_SetLed(&led_status, false, false);
			}
		}
		// Save new setup
		if (testbit(main_request, MAIN_REQUEST_SAVE_SETUP)) {
			clrbit(main_request, MAIN_REQUEST_SAVE_SETUP);
			main_SaveSetup();
			main_ReadSetup();
		}
	}
}

// Timers
ISR(RTC_OVF_vect) 
{
	setbit(main_request, MAIN_REQUEST_UPDATE_LED);
	setbit(main_request, MAIN_REQUEST_SCAN_KEYBOARD);
	counter_Update(&adc_conversion_timeout_ms, MAIN_TIMER_KEBOARD_MS);
	counter_Update(&timer_rtc_ms, MAIN_TIMER_KEBOARD_MS);
	if (counter_Check(&adc_conversion_timeout_ms)) setbit(*(pipo_status.errors), MAIN_ERROR_TIMEOUT_ADC);
	if (counter_Check(&timer_rtc_ms)) {
		counter_Reset(&timer_rtc_ms);
		counter_Update(&daemon_timeout_s, 1);
#ifdef CONFIG_UPS_INSTALLED
		counter_Update(&after_power_loss_s, 1);
#endif
		counter_Update(&delay_on_boot_s, 1);
		counter_Update(&delay_on_down_s, 1);
		counter_Update(&delay_on_pioff_s, 1);
	}
}

// ADC conversion complete
ISR(ADCA_CH0_vect) 
{
	setbit(main_request, MAIN_REQUEST_ADC_READY);
}
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

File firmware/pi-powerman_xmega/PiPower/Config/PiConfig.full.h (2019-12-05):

/*
 * PiConfig_custom.h
 *
 * Created: 2019-10-25 21:12:57
 * Atmel Studio 6 (Version: 6.2.1563 - Service Pack 2)
 *  Author: Krzysztof Markiewicz
 *  www.obbo.pl
 *
 * This program is distributed under the terms of the GNU General Public License
 */ 


#ifndef PICONFIG_H_
#define PICONFIG_H_



/*
	UPS module definition
*/
#define CONFIG_UPS_INSTALLED 
#define CONFIG_UPS_TYPE						"LTC4011 8*NiMh 1900mAh"
#define CONFIG_BATTERY_DISCHARGE_PORT		PORTA
#define CONFIG_BATTERY_DISCHARGE_PIN		3
#define CONFIG_BATTARY_TEMPERATURE_PORT		PORTA
#define CONFIG_BATTERY_TEMPERATURE_PIN		7

/*
	Measurement definition
*/
#define CONFIG_I2C_MEASUREMENT_INSTALLED
#define CONFIG_I2C_PORT						TWIE

#define CONFIG_ADC_MEASUREMENT_INSTALLED
#define CONFIG_ADC_REFERENCE_PORT			ADC_REFSEL_AREFA_gc
#define CONFIG_ADC_REFERENCE_EXT_MV			(2500)
//#define CONFIG_ADC_REFERENCE_VCC_MV			(3300)
#define CONFIG_ADC_MUX_PiState				ADC_CH_MUXPOS_PIN5_gc
#define CONFIG_ADC_MUX_V_In					ADC_CH_MUXPOS_PIN3_gc
#define CONFIG_ADC_MUX_V_Bat				ADC_CH_MUXPOS_PIN4_gc
#define CONFIG_ADC_MUX_BAT_Temp				ADC_CH_MUXPOS_PIN7_gc


/*
	Power output
*/
#define CONFIG_POWEROUT_Pi_port				PORTB
#define CONFIG_POWEROUT_Pi_pin				0
#define CONFIG_POWEROUT_1_port				PORTB
#define CONFIG_POWEROUT_1_pin				1
#define CONFIG_POWEROUT_2_port				PORTB
#define CONFIG_POWEROUT_2_pin				2
#define CONFIG_POWEROUT_3_port				PORTB
#define CONFIG_POWEROUT_3_pin				3
#define CONFIG_POWEROUT_4_port				PORTB
#define CONFIG_POWEROUT_4_pin				4
#define CONFIG_POWEROUT_5_port				PORTB
#define CONFIG_POWEROUT_5_pin				5
#define CONFIG_POWEROUT_6_port				PORTB
#define CONFIG_POWEROUT_6_pin				6
#define CONFIG_POWEROUT_7_port				PORTB
#define CONFIG_POWEROUT_7_pin				7

/* 
	Key config
*/
#define CONFIG_KEY_PWR_pin					0
#define CONFIG_KEY_PWR_port					PORTD
#define CONFIG_KEY_SW1_pin					1
#define CONFIG_KEY_SW1_port					PORTD
#define CONFIG_KEY_SW2_pin					2
#define CONFIG_KEY_SW2_port					PORTD
#define CONFIG_KEY_SW3_pin					3
#define CONFIG_KEY_SW3_port					PORTD
#define CONFIG_KEY_SW4_pin					4
#define CONFIG_KEY_SW4_port					PORTD
#define CONFIG_KEY_SW5_pin					5
#define CONFIG_KEY_SW5_port					PORTD
#define CONFIG_KEY_SW6_pin					6
#define CONFIG_KEY_SW6_port					PORTD
#define CONFIG_KEY_SW7_pin					7
#define CONFIG_KEY_SW7_port					PORTD

/*
	LED
*/
#define CONFIG_LED_STATUS_pin				0
#define CONFIG_LED_STATUS_port				PORTC
#define CONFIG_LED_PWR_pin					1
#define CONFIG_LED_PWR_port					PORTC
#define CONFIG_LED_SW1_pin					2
#define CONFIG_LED_SW1_port					PORTC
#define CONFIG_LED_SW2_pin					3
#define CONFIG_LED_SW2_port					PORTC
#define CONFIG_LED_SW3_pin					4
#define CONFIG_LED_SW3_port					PORTC
#define CONFIG_LED_SW4_pin					5
#define CONFIG_LED_SW4_port					PORTC
#define CONFIG_LED_SW5_pin					6
#define CONFIG_LED_SW5_port					PORTC
#define CONFIG_LED_SW6_pin					7
#define CONFIG_LED_SW6_port					PORTC
#define CONFIG_LED_SW7_pin					0	
#define CONFIG_LED_SW7_port					PORTE

/*
	Pi daemon
*/
#define CONFIG_PIDAEMON_INT_REQUEST_PORT	PORTC
#define CONFIG_PIDAEMON_INT_REQUEST_PIN		2

#define CONFIG_PIDAEMON_LOGIC_LEVEL_CHECK
#define CONFIG_PIDAEMON_STATE_PORT			PORTC
#define CONFIG_PIDAEMON_STATE_PIN			3



#endif /* PICONFIG_H_ */

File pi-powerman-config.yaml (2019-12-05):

# configuration file for pi-powerman.py

common:
    check_request_period_sec: 2
    check_pipower_period_sec: 150
    power_off_after_shutdown: true
    keepalive_period_sec: 90
        
export:
    destination:
        # uncomment required destination 
        - 'show'
        #- 'save'
        #- 'log'
        #- 'rrd'
        #- 'csv'
        # for IoT communication setup mqtt section 
        #- 'iot'
    #report in humane readable format (show, save, log)
    report_date_time_format: '%H:%M:%S on %Y %B %d'
    report_raw_data: true
    report_buttons_state: true
    report_pi_daemon_state: true
    report_supply_voltage: true
    report_bus_voltage: true
    report_current: true
    report_power: true
    report_outputs_state: true
    report_ups_state: true
    report_battery_voltage: true
    report_battery_temperature: true
    report_errors: true
    save_folder: '/usr/local/pi-powerman/'
    save_file: 'pi-powerman-status_%Y-%m-%d.log'
    save_last: false
    csv_folder: '/usr/local/pi-powerman/'
    csv_file: 'pi-powerman-status_%Y-%m-%d.csv'
    csv_decimal_mark: ','
    rrd_folder: '/var/www/pi-powerman/rrd/'
    rrd_graph_update: true
    # temperature_unit: 'K'(default), 'C', 'F'
    temperature_unit: 'C'
    iot_protocol: 'mqtt'
    iot_publish:
        - 'supply_voltage'
        - 'battery_voltage'
        - 'battery_temperature'
        - 'power'
        #- 'empty'
        #- 'bus_voltage'
        #- 'current'
        
log:
    # level: Control the severity of messages logged to the error_log.
    # Available values: CRITICAL, ERROR, WARNING, INFO, DEBUG
    level: INFO
    #level: DEBUG

mqtt:
    # 0 - unsecured_TCP (port 1883)
    # 1 - unsecured Websockets (port 80)
    # 2 - SSL Websockets (port 443)
    connection_type: 2
    host: 'mqtt.thingspeak.com'
    credential_file: '/usr/local/pi-powerman/pi-powerman.mqtt' 
    # Available data_format values: 'thingspeak', 'json', 'csv'
    data_format: 'thingspeak' 
    
# output supported on power module
outputs:
    # output aliases shown in the report
    aliases:
        OUT1: 'RasPi'
        OUT2: 'USB1'
        OUT3: 'USB2'
        OUT4: 'HDD'

factors:
    supply_voltage: 0.01
    battery_voltage: 0.01
    battery_temperature: 0.01
    bus_voltage: 0.0005
    current: 0.1
    power: 0.001

jobs:
    on_boot:
        timeout: 60
        commands:
            - '$clear_error DAEMON'
            - '$clear_error SYSTEM'
            - '$clear_error TIMEOUT_DAEMON'
            - '$press_button SW2 ON'
        on_failed: '$set_daemon_error'
    
    maintenance:
        #period: 600
        #timeout: 120
        #commands:
        #    - '/usr/local/pi-powerman/check_system_status.sh'
        #on_failed: '$set_daemon_error'
        
buttons:
    aliases:
        PWR: 'Power'
        SW1: 'WiFi'
        SW2: 'PPP'
        SW3: 'SW3'
    action:
    # set buttons behavior and scripts executed on event
    # available values: ON, TURN_OFF_01, TURN_OFF_02, TURN_OFF_03, TURN_OFF_04, OFF, TURN_ON_01, TURN_ON_02, TURN_ON_03, TURN_ON_04
    # if you not need script, leave option blank or comment line
    # set configuration for each button
        PWR:
            TURN_OFF_01: 
                timeout: 180
                commands:
                    - '/usr/local/pi-powerman/shut.sh'
            
        SW1:
            TURN_ON_01: 
                timeout: 120
                commands:
                    - '/root/wifi-start.sh'
                on_success: '$set_button SW1 ON'
                on_failed: '$set_button SW1 OFF'
                #on_exit(-1): '$set_button SW1 OFF'
                #on_exit(0): '$set_button SW1 ON'
                #on_exit(1): '$set_button SW1 OFF'
                #on_exit(2): '$set_button SW1 OFF'

            TURN_OFF_01: 
                timeout: 60
                commands:
                    - '/root/wifi-stop.sh'
                on_success: '$set_button SW1 OFF'
                on_failed: '$set_button SW1 ON'
                
            #check:
            #    period: 600
            #    timeout: 60
            #    commands:
            #        - '/root/wifi-check.sh'
            #    on_success: '$set_button SW1 ON'
            #    on_failed: '$set_button SW1 OFF'
                
        SW2:
            TURN_ON_01: 
                timeout: 180
                commands:
                    - '$set_output OUT2 ON'
                    - '$wait 40'
                    - '/usr/local/pi-powerman/ppp0_start.sh'
                on_success: '$set_button SW2 ON'
                on_failed: '$set_button SW2 OFF'

            TURN_OFF_01: 
                timeout: 120
                commands:
                    - '/usr/local/pi-powerman/ppp0_stop.sh'
                    - '$wait 20'
                    - '$set_output OUT2 OFF'
                on_success: '$set_button SW2 OFF'
                on_failed: '$set_button SW2 ON'
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

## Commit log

2019-04-27 schematic in .png
2019-05-12 add UPS info
    [pi-powerman-hardware.yaml]
2019-05-18 change: OUTPUT_BUFFER_SIZE, change: command code
    [pi-powerman-hardware.yaml]
2019-05-18 change: data frame format
2019-05-19 add: hardware features info
    [pi-powerman-hardware.yaml]
2019-05-24 add: features recognition
    [pi-powerman-hardware.yaml]
2019-06-06 update configuration template
    [pi-powerman-hardware.yaml]
2019-12-04 symbols update
    [pi-powerman_4i2o1pu_xmega128a4u_190115.sch, pi-powerman_ups_8xNiMh_190115.sch]
2019-12-04 new sample hardware
    [pi-powerman_3i1o_xmega32e5_190428.kicad_pcb, pi-powerman_3i1o_xmega32e5_190428.sch]
2019-12-05 new options in setup and upgrade to support the latest firmware version
    [pi-powerman-hardware.yaml]
